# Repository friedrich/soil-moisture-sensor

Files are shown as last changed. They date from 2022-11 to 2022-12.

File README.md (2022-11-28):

# Moisture sensor

A capacitive moisture sensor board employing an ESP32-C3 RISC-V microcontroller
capable of transmitting measurements via Wi-Fi and Bluetooth 5 (LE). The board
is powered by a single cell LiPo battery, which can be charged using the USB-C
port.

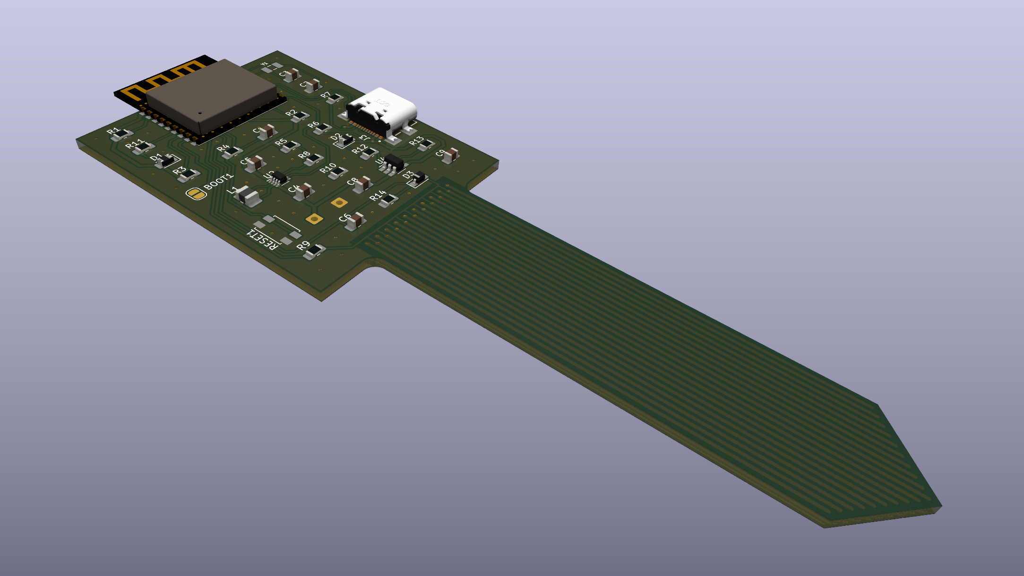
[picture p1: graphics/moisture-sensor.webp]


Components are spaced quite far apart, with the goal of making it easier to
solder them by hand.

## Sensor circuit

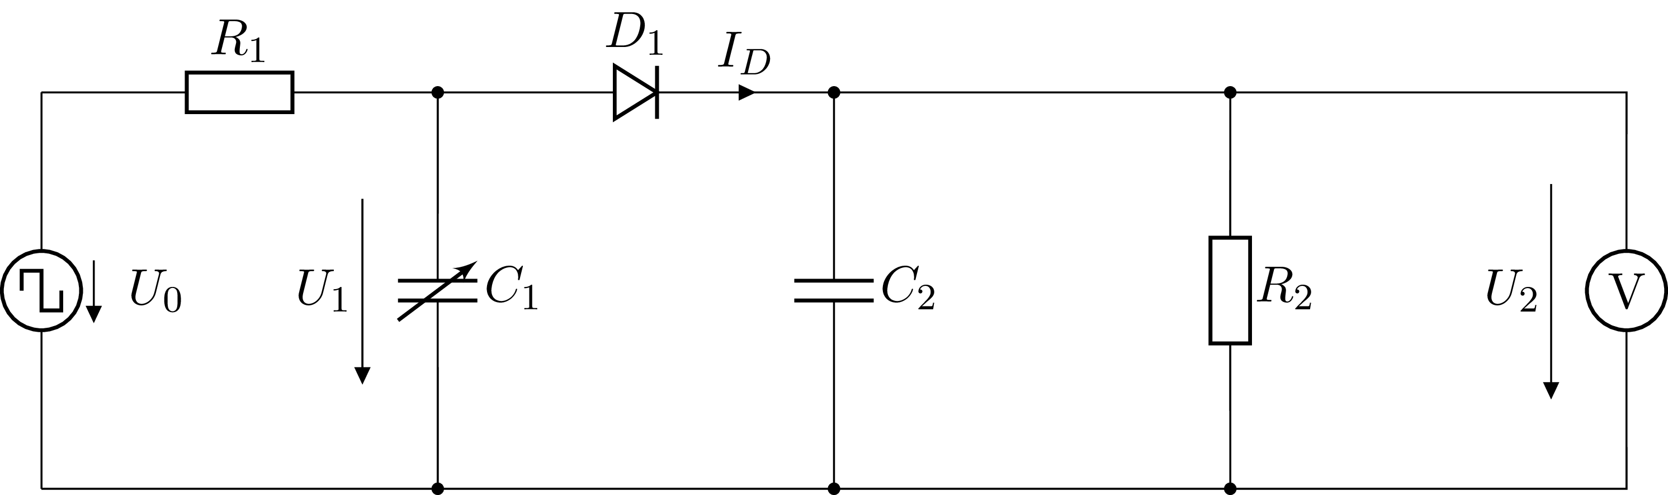
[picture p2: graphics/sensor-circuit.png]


The sensor circuit consists of the following building blocks:
- The microcontroller generating a square wave, depicted as voltage source
  $U_0$.
- A low pass filter made up of resistor $R_1$ and capacitor $C_1$. Capacitor
  $C_1$ stands for sensor wires together with the medium to be measured acting
  as a dielectric. Its value is to be determined by the circuit.
- A peak voltage detector made up of diode $D_1$, resistor $R_2$ and capacitor
  $C_2$.
- The microcontroller measuring voltage $U_2$.

Since resistor $R_2$ is chosen to be quite large, the impact of the peak voltage
detector on the low pass filter becomes negligible, as soon as $C_2$ reaches a
stable voltage. Just considering the voltage source together with the low pass
filter leads to a peak voltage of

$$ U_p = U_+ \frac{1 - e^{-\omega T D}}{1 - e^{-\omega T}}, $$

where $U_+$ is the high voltage of the voltage source, $T$ the period, $D$ the
duty cycle, and $\omega = 1/(R_1 C_2)$. The peak voltage has a range from $U_+$
for zero $C_2$ down to $D U_+$ for infinite $C_2$.

## Possible future circuit improvements

- Add battery protection circuit.
- Add a switch for turning the device on and off.
- Add a button to put the device into a mode where it acts as an access point or
  can be connected via Bluetooth.
- Make it possible for the microcontroller to measure battery voltage and to
  know if it is powered using USB or the battery. Detect USB using an RTC GPIO
  port to be able to wake the microcontroller when plugged in.
- Replace the battery solder pads with a connector.
- Remove sensing traces from the top so that it matters less how deep the sensor
  is pushed into the soil. Additionally, moisture variations are more relevant
  deeper down than on the top.
- Increase the length of the probe.
- Make it possible to power the board without a battery, using USB-C only. This
  is currently possible by bypassing the battery charge management controller by
  connecting VDD and +BATT. Otherwise, the power supply voltage of the
  microcontroller is not stable.
- Expose JTAG pins for development since the USB-to-JTAG interface is turned off
  during deep sleep.

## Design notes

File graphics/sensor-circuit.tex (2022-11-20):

\documentclass[tikz,11pt]{standalone}

\usepackage{tikz}
\usepackage{circuitikz}

\standaloneenv{circuitikz}

\ctikzset{
  diodes/scale=0.8,
  capacitors/width=0.15,
  bipoles/length=1cm,
}

\begin{document}
\begin{circuitikz}[european, straight voltages, scale=3]
  \draw (0,1)
  to[sqV,v=$U_0$] (0,0);

  \draw (0,1)
  to[R=$R_1$, -*] (1,1)
  to[vC=$C_1$, v=$U_1$, -*, invert] (1,0);

  \draw(1,1)
  to[Do=$D_1$, i=$I_D$, -*] (2,1)
  to[C=$C_2$, -*] (2,0);

  \draw (2,1)
  to[short, -*] (3,1)
  to[R=$R_2$, -*] (3,0);

  \draw (3,1)
  to[short] (4,1)
  to[rmeter, t=V, v=$U_2$] (4,0)
  to[short] (0,0);
\end{circuitikz}
\end{document}

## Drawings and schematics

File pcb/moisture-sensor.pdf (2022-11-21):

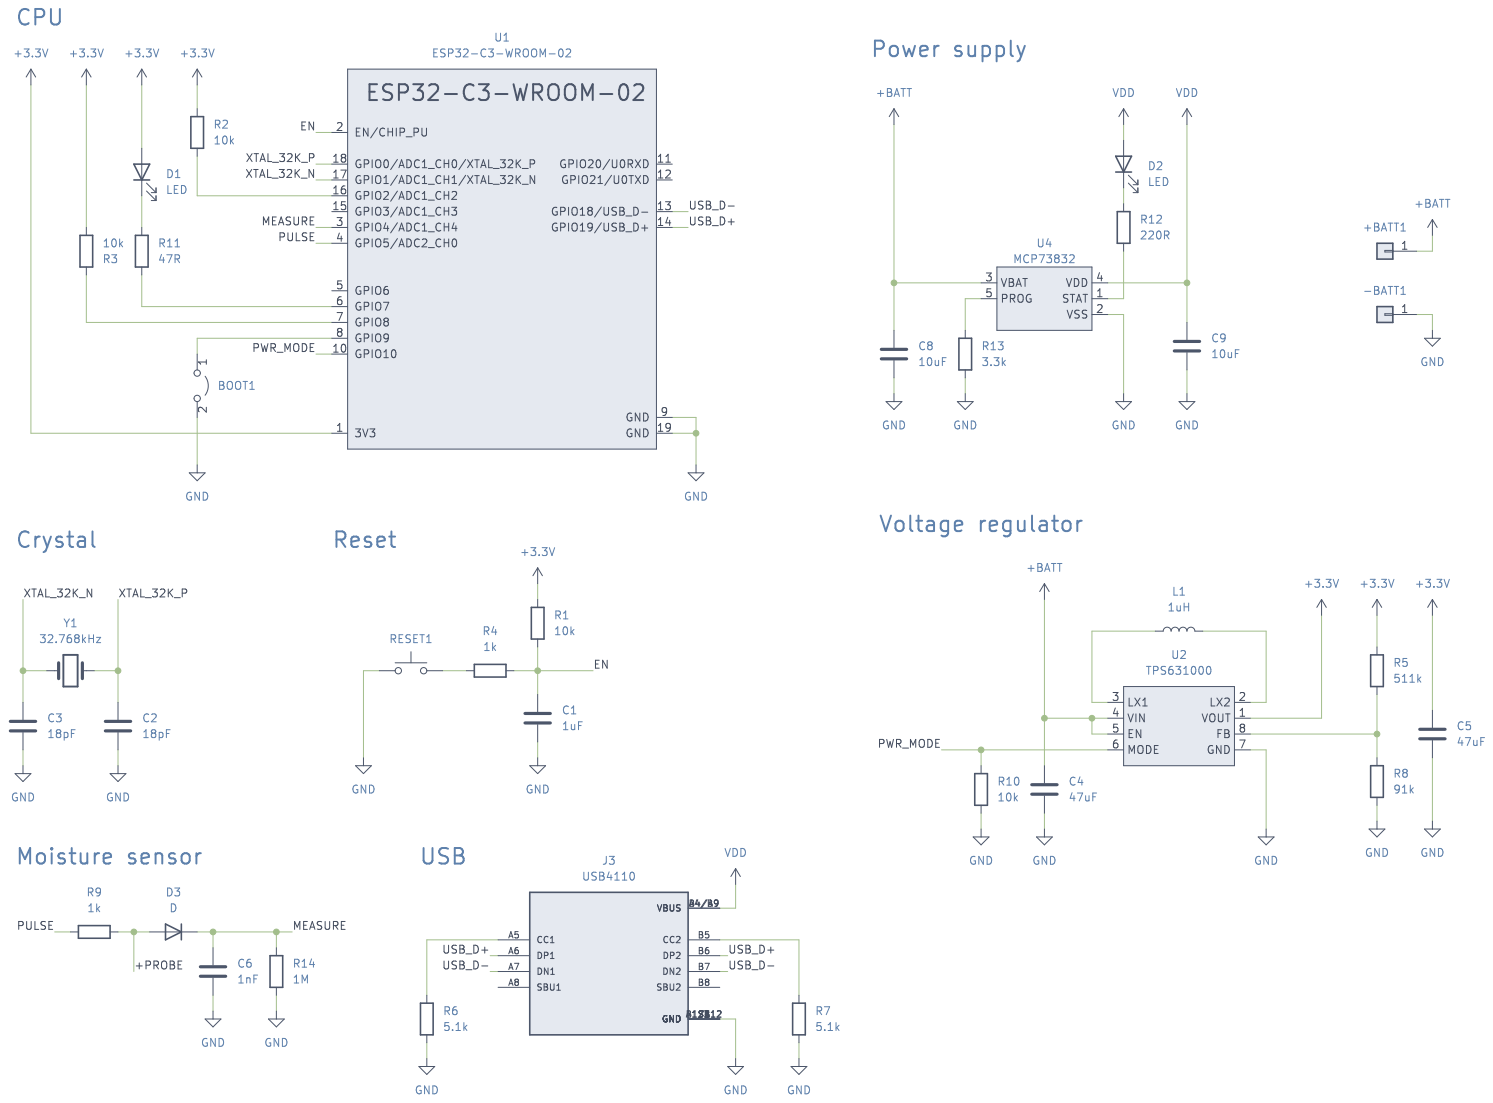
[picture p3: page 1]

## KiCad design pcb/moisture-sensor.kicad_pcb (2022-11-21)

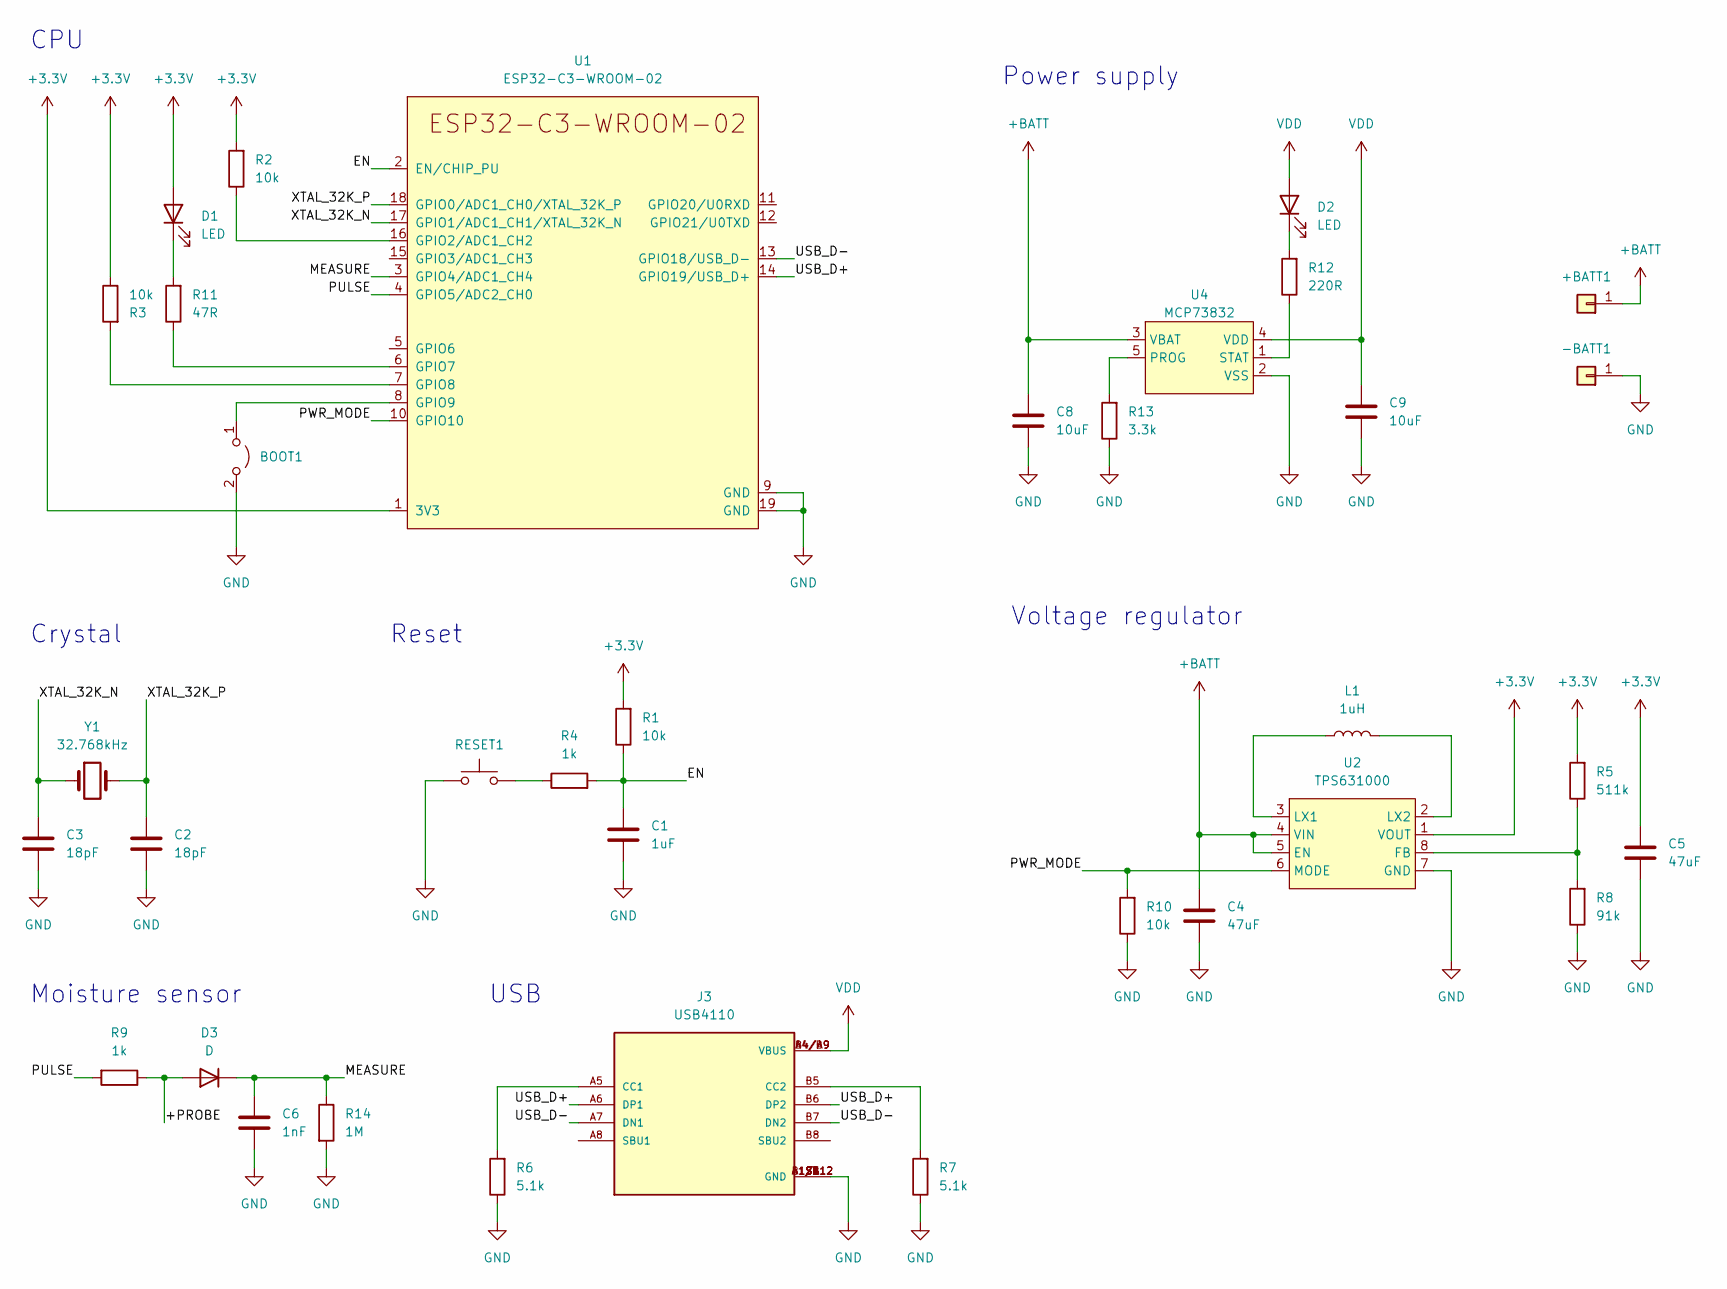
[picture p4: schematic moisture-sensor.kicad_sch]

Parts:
+BATT1: Conn_01x01; SolderWire-0.25sqmm_1x01_D0.65mm_OD1.7mm
-BATT1: Conn_01x01; SolderWire-0.25sqmm_1x01_D0.65mm_OD1.7mm
BOOT1: Jumper_2_Open; SolderJumper-2_P1.3mm_Open_RoundedPad1.0x1.5mm
C1: 1uF; C_0805_2012Metric_Pad1.18x1.45mm_HandSolder; MPN GRM219R7YA105KA12
C2, C3: 18pF; C_0805_2012Metric_Pad1.18x1.45mm_HandSolder; MPN GRM21A5C2E180JW01
C4, C5: 47uF; C_0805_2012Metric_Pad1.18x1.45mm_HandSolder; MPN GRM21BR61A476ME15
C6: 1nF; C_0805_2012Metric_Pad1.18x1.45mm_HandSolder; MPN GRM2165C2A102JA01
C8, C9: 10uF; C_0805_2012Metric_Pad1.18x1.45mm_HandSolder; MPN GRM21BR71A106KA73
D1, D2: LED; D_0805_2012Metric_Pad1.15x1.40mm_HandSolder; MPN LTST-C170KGKT
D3: D; D_SOD-323_HandSoldering; MPN BAV16WS-7-F
J3: USB4110; USB4110-GF-A_REVB; MPN USB4110-GF-A
L1: 1uH; L_1008_2520Metric_Pad1.43x2.20mm_HandSolder; MPN DFE252012P-1R0M=P2
R1, R2, R3, R10: 10k; R_0805_2012Metric_Pad1.20x1.40mm_HandSolder; MPN RC0805FR-0710KL
R4, R9: 1k; R_0805_2012Metric_Pad1.20x1.40mm_HandSolder; MPN RC0805FR-071KL
R5: 511k; R_0805_2012Metric_Pad1.20x1.40mm_HandSolder; MPN RC0805FR-07511KL
R6, R7: 5.1k; R_0805_2012Metric_Pad1.20x1.40mm_HandSolder; MPN RC0805FR-075K1L
R8: 91k; R_0805_2012Metric_Pad1.20x1.40mm_HandSolder; MPN RC0805FR-0791KL
R11: 47R; R_0805_2012Metric_Pad1.20x1.40mm_HandSolder; MPN RC0805FR-0747RL
R12: 220R; R_0805_2012Metric_Pad1.20x1.40mm_HandSolder; MPN RC0805FR-07220RL
R13: 3.3k; R_0805_2012Metric_Pad1.20x1.40mm_HandSolder; MPN RC0805FR-073K3L
R14: 1M; R_0805_2012Metric_Pad1.20x1.40mm_HandSolder; MPN RC0805FR-071ML
RESET1: EVQ-Q2F03W; SW_SPST_EVQP2; MPN EVQ-P2K02Q
U1: ESP32-C3-WROOM-02; MPN ESP32-C3-WROOM-02-N4
U2: TPS631000; SC-70-8; MPN TPS631000DRLR
U4: MCP73832; SOT-23-5_HandSoldering; MPN MCP73832T-2DCI/OT
Y1: 32.768kHz; Crystal_SMD_G8-2Pin_3.2x1.5mm_HandSoldering; MPN ABS07-32.768KHZ-T

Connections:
+3.3V: C5.1, D1.2 (A), R1.2, R2.2, R3.1, R5.2, U1.1 (3V3), U2.1 (VOUT)
+BATT: +BATT1.1, C4.1, C8.2, U2.4 (VIN), U2.5 (EN), U4.3 (VBAT)
/+PROBE: D3.2 (A), R9.1
/EN: C1.2, R1.1, R4.2, U1.2 (EN/CHIP_PU)
/MEASURE: C6.1, D3.1 (K), R14.1, U1.3 (GPIO4/ADC1_CH4)
/PULSE: R9.2, U1.4 (GPIO5/ADC2_CH0)
/PWR_MODE: R10.2, U1.10 (GPIO10), U2.6 (MODE)
/USB_D+: J3.A6 (DP1), J3.B6 (DP2), U1.14 (GPIO19/USB_D+)
/USB_D-: J3.A7 (DN1), J3.B7 (DN2), U1.13 (GPIO18/USB_D-)
/XTAL_32K_N: C3.2, U1.17 (GPIO1/ADC1_CH1/XTAL_32K_N), Y1.1
/XTAL_32K_P: C2.2, U1.18 (GPIO0/ADC1_CH0/XTAL_32K_P), Y1.2
GND: -BATT1.1, BOOT1.2 (B), C1.1, C2.1, C3.1, C4.2, C5.2, C6.2, C8.1, C9.1, J3.A1/B12 (GND), J3.B1/A12 (GND), J3.S1 (GND), J3.S2 (GND), J3.S3 (GND), J3.S4 (GND), R6.1, R7.1, R8.1, R10.1, R13.1, R14.2, RESET1.1, U1.9 (GND), U1.19 (GND), U2.7 (GND), U4.2 (VSS)
unnamed: BOOT1.1 (A), U1.8 (GPIO9)
unnamed: D1.1 (K), R11.2
unnamed: D2.1 (K), R12.2
unnamed: J3.A5 (CC1), R6.2
unnamed: J3.B5 (CC2), R7.2
unnamed: L1.1, U2.3 (LX1)
unnamed: L1.2, U2.2 (LX2)
unnamed: R2.1, U1.16 (GPIO2/ADC1_CH2)
unnamed: R3.2, U1.7 (GPIO8)
unnamed: R4.1, RESET1.2
unnamed: R5.1, R8.2, U2.8 (FB)
unnamed: R11.1, U1.6 (GPIO7)
unnamed: R12.1, U4.1 (STAT)
unnamed: R13.2, U4.5 (PROG)
VDD: C9.2, D2.2 (A), J3.A4/B9 (VBUS), J3.B4/A9 (VBUS), U4.4 (VDD)

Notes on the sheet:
Power supply
Crystal
Moisture sensor
Voltage regulator
CPU
Reset
USB

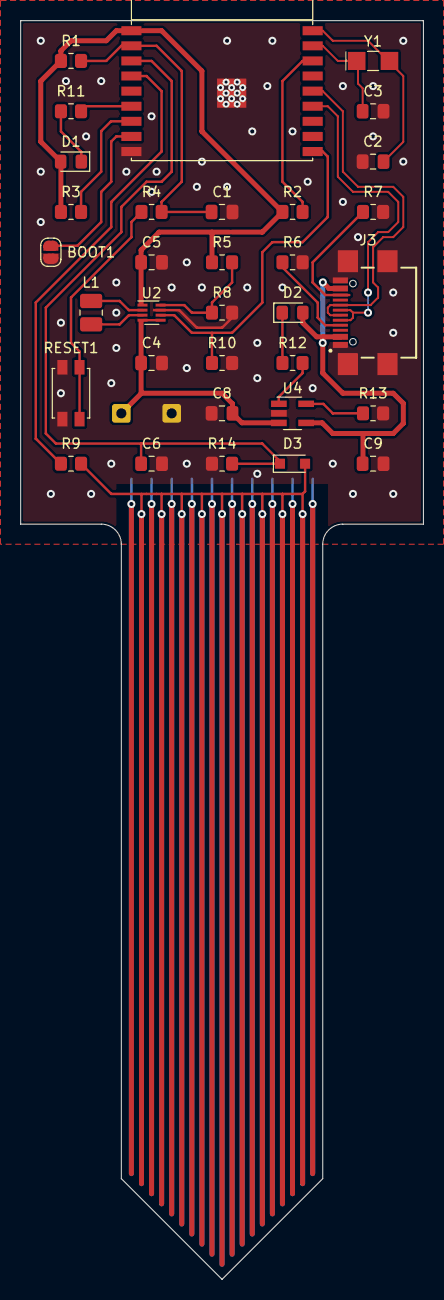
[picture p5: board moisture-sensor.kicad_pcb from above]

Board: 2 copper layers, 40.0 x 125.0 mm, 35 parts (0 on the bottom side), 27 nets.

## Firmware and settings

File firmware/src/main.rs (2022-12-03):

mod arr_deque;

use crate::arr_deque::ArrDeque;
use anyhow::{anyhow, bail, Context, Result};
use chrono::Utc;
use embedded_svc;
use embedded_svc::http::Method;
use embedded_svc::io::Write;
use esp_idf_hal::units::FromValueType;
use esp_idf_hal::{adc, gpio, ledc, reset};
use esp_idf_hal::{delay::FreeRtos, peripherals};
use esp_idf_svc::netif::IpEvent;
use esp_idf_svc::wifi::{EspWifi, WifiEvent};
use esp_idf_svc::{eventloop, nvs, sntp};
use std::sync::mpsc::channel;
use std::time::Duration;

const WIFI_SSID: &str = env!("WIFI_SSID");
const WIFI_PASSWORD: &str = env!("WIFI_PASSWORD");

const WRITE_URL: &str = env!("WRITE_URL");
const AUTHORIZATION: &str = env!("AUTHORIZATION");
const LINE_PREFIX: &str = env!("LINE_PREFIX");

const MEASUREMENT_INTERVAL: Duration = Duration::from_secs(3600);
const MIN_RECORDED_MEASUREMENTS: usize = 6;
const MAX_RECORDED_MEASUREMENTS: usize = 1000;

#[derive(Clone)]
struct Measurement {
    value: u16,
    time: u32,
}

#[link_section = ".rtc.data.rtc_memory"]
static mut MEASUREMENTS: ArrDeque<Measurement, MAX_RECORDED_MEASUREMENTS> = ArrDeque::new();

fn main() -> Result<()> {
    esp_idf_sys::link_patches();

    if let Err(e) = run() {
        println!("error: {}", e);
    }

    unsafe {
        go_to_sleep();
    }
}

fn run() -> Result<()> {
    let peripherals = peripherals::Peripherals::take().context("peripherals already taken")?;
    let mut led_driver = gpio::PinDriver::output(peripherals.pins.gpio7)?;

    let mut power_mode_driver = gpio::PinDriver::output(peripherals.pins.gpio10)?;
    power_mode_driver.set_high()?;

    let mut adc_driver = adc::AdcDriver::new(
        peripherals.adc1,
        &adc::config::Config::new().calibration(true),
    )?;
    let mut adc_channel_driver: adc::AdcChannelDriver<gpio::Gpio4, adc::Atten11dB<_>> =
        adc::AdcChannelDriver::new(peripherals.pins.gpio4)?;

    let pwm_config = ledc::config::TimerConfig::new().frequency(50.kHz().into());
    let mut sensor_pwm_driver = ledc::LedcDriver::new(
        peripherals.ledc.channel0,
        ledc::LedcTimerDriver::new(peripherals.ledc.timer0, &pwm_config)?,
        peripherals.pins.gpio5,
        &pwm_config,
    )?;

    let clock_source = unsafe { esp_idf_sys::rtc_clk_slow_freq_get() };
    if clock_source != esp_idf_sys::rtc_slow_freq_t_RTC_SLOW_FREQ_32K_XTAL {
        bail!("wrong slow clock source");
    }

    if reset::ResetReason::get() != reset::ResetReason::DeepSleep {
        greeting(&mut led_driver)?;
    } else {
        led_driver.set_high()?;
    }

    sensor_pwm_driver.set_duty(sensor_pwm_driver.get_max_duty() / 100)?;
    FreeRtos::delay_ms(20); // TODO: good value?

    match adc_driver.read(&mut adc_channel_driver) {
        Ok(value) => {
            let time = slow_clock_seconds();
            println!("recorded value: {} at {}", value, time);

            unsafe {
                MEASUREMENTS.overwriting_push_back(Measurement { value, time });
                if MEASUREMENTS.len() < MIN_RECORDED_MEASUREMENTS {
                    return Ok(());
                }
            }
        }
        Err(e) => {
            bail!("error measuring: {}", e);
        }
    };

    let sysloop = eventloop::EspSystemEventLoop::take()?;
    let nvs_partition = nvs::EspDefaultNvsPartition::take()?;

    let mut esp_wifi = EspWifi::new(peripherals.modem, sysloop.clone(), Some(nvs_partition))?;
    esp_wifi.set_configuration(&embedded_svc::wifi::Configuration::Client(
        embedded_svc::wifi::ClientConfiguration {
            ssid: WIFI_SSID.into(),
            password: WIFI_PASSWORD.into(),
            channel: None,
            ..Default::default()
        },
    ))?;

    let (wifi_started_tx, wifi_started_rx) = channel();
    let (wifi_connected_tx, wifi_connected_rx) = channel();
    let _wifi_subscription = sysloop.subscribe(move |event: &WifiEvent| match event {
        WifiEvent::StaStarted => {
            let _ = wifi_started_tx.send(());
        }
        WifiEvent::StaConnected => {
            let _ = wifi_connected_tx.send(Ok(()));
        }
        WifiEvent::StaDisconnected => {
            let _ = wifi_connected_tx.send(Err(anyhow!("WiFi disconnected")));
        }
        _ => {}
    })?;

    let (ip_assigned_tx, ip_assigned_rx) = channel();
    let _netif_subscription = sysloop.subscribe(move |event: &IpEvent| match event {
        IpEvent::DhcpIpAssigned(_) | IpEvent::DhcpIp6Assigned(_) => {
            let _ = ip_assigned_tx.send(());
        }
        _ => {}
    })?;

    esp_wifi.start()?;

    wifi_started_rx.recv()?;
    println!("connecting WiFi...");
    esp_wifi.connect()?;

    wifi_connected_rx.recv()??;
    println!("WiFi connected.");

    ip_assigned_rx.recv()?;
    println!("IP address obtained, syncing time....");

    let sntp = sntp::EspSntp::new_default()?;
    while sntp.get_sync_status() != sntp::SyncStatus::Completed {
        FreeRtos::delay_ms(100);
    }
    println!("time synced, sending data..");

    let time_offset = Utc::now().timestamp() - slow_clock_seconds() as i64;

    let measurements: Vec<_> = unsafe { MEASUREMENTS.iter().cloned().collect() };
    send_values(measurements.as_slice(), time_offset)?;
    println!("successfully sent data.");

    unsafe {
        MEASUREMENTS = ArrDeque::new();
    }

    Ok(())
}

fn slow_clock_seconds() -> u32 {
    let rtc_time = unsafe { esp_idf_sys::rtc_time_get() };
    (rtc_time / u64::from(esp_idf_sys::RTC_SLOW_CLK_FREQ_32K)) as _
}

fn greeting<T: gpio::Pin, MODE: gpio::OutputMode>(
    led_pin: &mut gpio::PinDriver<T, MODE>,
) -> Result<()> {
    for _ in 0..4 {
        led_pin.set_low()?;
        FreeRtos::delay_ms(20);
        led_pin.set_high()?;
        FreeRtos::delay_ms(100);
    }
    FreeRtos::delay_ms(400);
    led_pin.set_low()?;
    FreeRtos::delay_ms(1000);
    led_pin.set_high()?;
    FreeRtos::delay_ms(500);

    Ok(())
}

unsafe fn go_to_sleep() -> ! {
    let delay = MEASUREMENT_INTERVAL.as_micros() as _;
    esp_idf_sys::esp_sleep_enable_timer_wakeup(delay);
    esp_idf_sys::esp_deep_sleep_start();
    unreachable!();
}

fn send_values(measurements: &[Measurement], time_offset: i64) -> anyhow::Result<()> {
    let http_client_config = esp_idf_svc::http::client::Configuration {
        crt_bundle_attach: Some(esp_idf_sys::esp_crt_bundle_attach),
        ..Default::default()
    };

    let data: String = measurements
        .iter()
        .map(|m| {
            format!(
                "{}{} {}000000000\n",
                LINE_PREFIX,
                m.value,
                m.time as i64 + time_offset
            )
        })
        .collect();

    println!("{}", data);

    let content_length = data.len().to_string();
    let headers = vec![
        ("Authorization", AUTHORIZATION),
        ("Content-Length", &content_length),
    ];

    let mut http_client = esp_idf_svc::http::client::EspHttpConnection::new(&http_client_config)?;
    http_client.initiate_request(Method::Post, WRITE_URL, &headers)?;
    http_client.write_all(data.as_bytes())?;
    http_client.initiate_response()?;

    let status = http_client.status();
    if status < 200 || status >= 300 {
        let mut response = vec![0; 1000];
        http_client.read(&mut response)?;
        bail!(
            "HTTP status {}: {}",
            status,
            String::from_utf8_lossy(&response)
        );
    }

    Ok(())
}

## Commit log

2022-11-08 create first PCB version
    [moisture-sensor.kicad_pcb, moisture-sensor.kicad_sch]
2022-11-08 improve PCB
    [moisture-sensor.kicad_pcb, moisture-sensor.kicad_sch]
2022-11-09 add footprints and 3d models, increase solder pad size
    [moisture-sensor.kicad_pcb, moisture-sensor.kicad_sch]
2022-11-09 adjust some component values
    [moisture-sensor.kicad_pcb, moisture-sensor.kicad_sch]
2022-11-20 add battery text
    [moisture-sensor.kicad_pcb]
2022-11-20 fix reset button
    [moisture-sensor.kicad_pcb, moisture-sensor.kicad_sch]
2022-11-20 clarify sensor circuit
2022-11-21 add datasheet to schematic
    [moisture-sensor.kicad_sch]
2022-11-21 update KiCad file version
    [moisture-sensor.kicad_pcb]
2022-11-21 add schematic as PDF
2022-11-21 prefer built in KiCad items
    [moisture-sensor.kicad_pcb, moisture-sensor.kicad_sch]
2022-11-26 add note about peak voltage range
2022-11-26 increase power supply capacitor sizes
    [moisture-sensor.kicad_pcb, moisture-sensor.kicad_sch]
2022-11-27 Revert "increase power supply capacitor sizes"
    This reverts commit e628d20ff7827fca777ef456cf9c7b65b2cb21d5.
    [moisture-sensor.kicad_pcb, moisture-sensor.kicad_sch]
2022-11-27 add note about power supply
2022-11-28 print recorded value
